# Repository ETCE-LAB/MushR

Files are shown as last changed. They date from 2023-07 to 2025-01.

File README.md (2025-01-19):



# MushR

MushR is a modular and scalable gourmet mushroom growing and
harvesting system that goes beyond the state of the art, which merely
monitors and controls the growing environment, by introducing an image
recognition system that determines when and which mushrooms are ready
to be harvested in conjunction with a proof-of-concept of an automated
mushroom harvesting mechanism for harvesting the mushrooms without
human interaction. The image recognition setup monitors the growing
status of the mushrooms and guides the harvesting process. We present
a Mask R-CNN model for the detection of oyster mushroom maturity as
well as a semi-automated harvesting system, integrating a Raspberry Pi
for control, an electrical switch, an air compressor, and a pneumatic
cylinder with a cutting knife to facilitate timely mushroom
harvesting. The modularity and scalability of the system allow for
industry-level usage and can be scaled according to the required
mushroom-growing systems within the facility.

The dataset created for this project focuses on capturing images of
the mushroom-growing environment from three different perspectives
within each of our two growth tents for mushroom production. Instead
of providing images of every individual bucket and mushroom, we
capture the overall scene and its variations. The images from each
perspective are captured simultaneously and automatically hourly. This
approach allows for monitoring the development and maturity of the
oyster mushrooms over time. We captured and accumulated 34,400 images
over ten months to ensure a comprehensive dataset.

- [Growchamber Setup](growchamber-setup/)
- [Automated Image Capture](automated-image-capture/) 

- [Lifecycle Assessment Calculations](lca-calculations/)
- MushR Digital Twin
  - [MushR Digital Twin API](https://github.com/ETCE-LAB/mushr-digitaltwin-api/tree/main)
  - [MushR Digital Twin Widgets for MyCodo](https://github.com/ETCE-LAB/mushr-digitaltwin-api/tree/main/mycodo)
- MushR Dataset
  - [Complete Un-Annotated RAW Images](https://www.kaggle.com/datasets/etcelab/mushr-project-raw-image-dataset-oyster-mushrooms)
  - [Images annotated for Mask R CNN](https://www.kaggle.com/datasets/etcelab/mushr-annotated-dataset-oyster-mushrooms)
  - [MushR Mask R CNN](https://github.com/ETCE-LAB/mushr-mask-r-cnn)
- Harvesting Setup
 - [Pneumatic Harvesting](pneumatic-harvesting/)
 - [Motorized Harvesting](motorized-harvesting/)

# Contributors (Past and Present)

1. Anant Sujatanagarjuna
2. Shohreh Kia
3. Harish Gundelli

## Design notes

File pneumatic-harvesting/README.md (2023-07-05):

## Contributors
  1. Shohreh Kia
  2. Anant Sujatanagarjuna

## Pneumatic Harvesting of Oyster Mushrooms

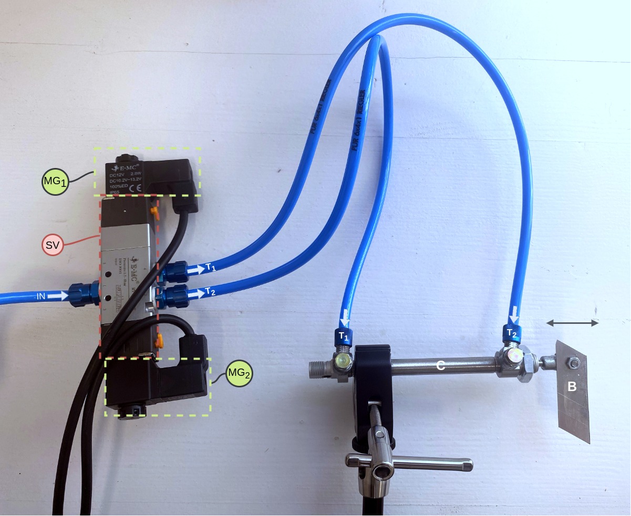
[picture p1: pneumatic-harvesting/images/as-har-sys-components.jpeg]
Pneumatic Harvesting Components 1

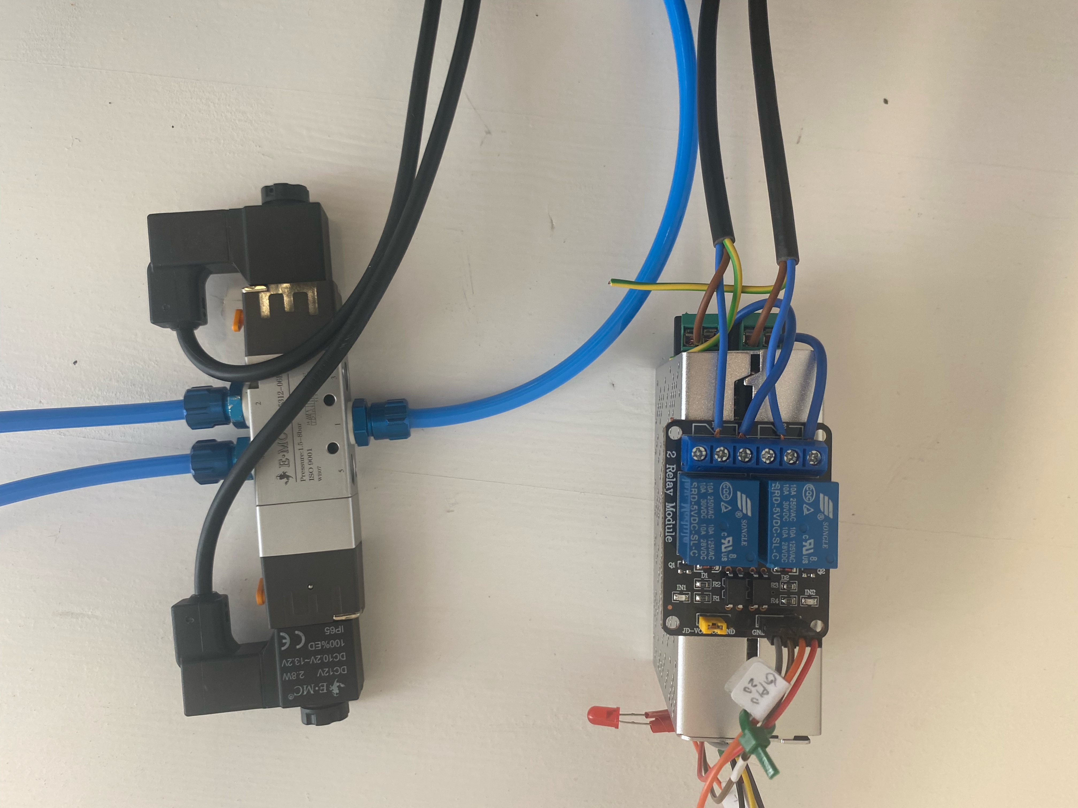
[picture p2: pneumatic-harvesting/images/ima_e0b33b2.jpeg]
Pneumatic Harvesting Components 2


The above figures show the components used to prototype a pneumatic
harvesting system for Oyster mushrooms.

## Working Principle

This system actuates a blade (B) which is mounted perpendicularly on a
bi-directional pneumatic cylinder (C). The cylinder is set up to
harvest oyster mushrooms growing from our developed mushroom pods. The
pneumatic tubes T1 and T2 control the motion of the pneumatic
cylinder. Depending on whether T1 or T2 is pressurized, the piston rod
moves outwards or inwards from the cylinder, respectively. When both
T1 and T2 are pressurized or depressurized, the piston is immobilized
or free to move, respectively.

For the purpose of harvesting, T1 and T2 must be pressurized and
depressurized alternatively. This is accomplished by the 5/3-way
solenoid valve (SV). Internally, two solenoids control the valves
pressurizing T1 and T2. These solenoids are activated by 12-volt DC
magnetic coils MG1 and MG2 . These coils are digitally controlled by
5-volt relay switches connected to a Raspberry Pi 4B, programmatically
controlling the entire setup.

For simplicity, we use a an analog joystick to control the 5-volt
relays, however it is also possible for them to be actuated remotely
and automatically.

## Connection Diagram

Connection Diagram

The above ciruit diagram was created using
[Fritzing](https://github.com/fritzing/).

`joystick_control.sh` is the accompanying control script.

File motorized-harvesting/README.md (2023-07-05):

## Contributors
  1. Shohreh Kia

## Motorized Harvesting of Oyster Mushrooms

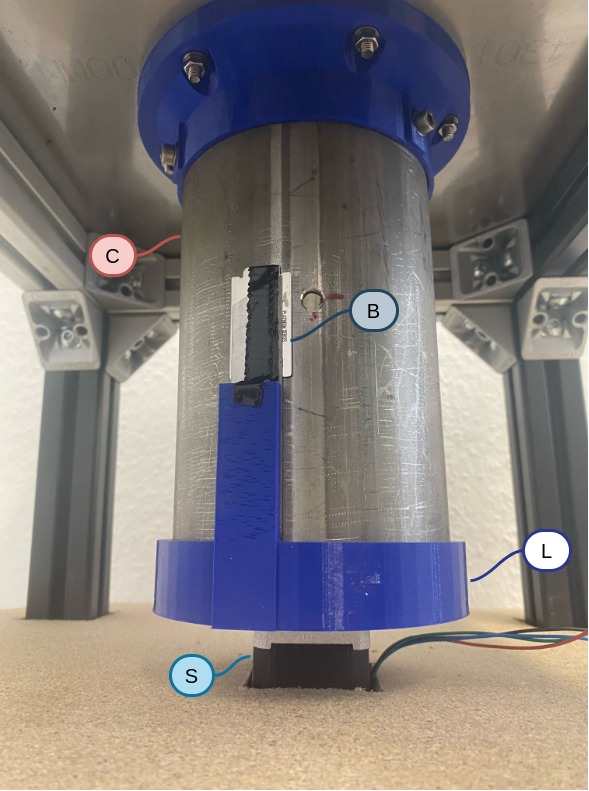
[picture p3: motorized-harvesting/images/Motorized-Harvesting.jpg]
Motorized Harvesting Components


The above figures show the components used to prototype a pneumatic
harvesting system for Oyster mushrooms.

## Working Principle

The above figure shows the major components of the developed motorized
harvesting system, which consists of a stainless steel cylinder (C)
with fruiting holes suspended from the ceiling of a stool constructed
using item profiles. The cylinder contains a plastic bag filled with a
substrate for oyster mushroom growth. These holes on the cylinder
aligned with the perforation in the plastic bag, allowing the
mushrooms to emerge and grow. A 3D-printed lid (L), matching the
diameter of the cylinder, seals the bottom to prevent substrate
spillage in case of damage to the bag. A stepper motor (S) is
installed underneath the suspended cylinder to drive a 3D-printed
plate, which vertically holds the blade (B).  The plate is
specifically designed to accommodate the motor, ensuring stability
during rotation.

The stepper motor initiates rotation, causing the blade to cut the
mushrooms protruding through the holes in the cylinder. We program the
motor to rotate in either direction to ensure successful
harvesting. Adjustments such as sharpening the knife and modifying the
motor’s speed can be made to optimize the system’s performance.

## Connection Diagram

Connection Diagram

## CAD Files

The CAD files for the 3D printed components used for this system can be found in [](cad/)

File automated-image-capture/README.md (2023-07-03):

# Table of Contents

1.  [Software Installation](#org174f0ca)
    1.  [Operating System](#org78977bb)
        1.  [Tent1Pi](#orgb3c0dfb)
        2.  [LightingPi](#orgb3e6948)
        3.  [Tent2Pi](#org14200cd)
2.  [Hardware Installation Guide](#orga6efd23)
    1.  [Focus adjustment](#org7833075)
    2.  [Waterproofing the cameras](#orgb9a1131)
    3.  [Installing the cameras in the tents](#org29d7754)
        1.  [Installing the aluminium mounts](#orga788bbe)
        2.  [Clamping the cameras](#org661947b)
    4.  [Raspberry Pi <-> Camera connection](#org06773e6)
    5.  [Lighting Setup](#org10030a2)

It is reccommended follow the following steps **IN ORDER**.

# Software Installation

## Operating System

-   The setup has only been tested with Raspberry Pi OS 32-bit on a
    Rpi4B (the version at the time of writing this guide is:
    <https://downloads.raspberrypi.org/raspios_armhf/images/raspios_armhf-2022-09-26/>)

-   Follow [this guide](https://www.raspberrypi.com/software/) to install your desired OS version.

-   Be sure to enable the SSH daemon and test that you are able to
    remotely log in to each pi using the password you chose during
    install.
    
        sudo systemctl enable sshd.service

-   Please also enable autologin (desktop/TTY) at least for [1.1.3](#org14200cd)
    
    For [1.1.1](#orgb3c0dfb) and [1.1.3](#org14200cd), you must verify whether the cameras are
    functioning using [this guide](https://www.raspberrypi.com/documentation/computers/camera_software.html) (might require a monitor and keyboard
    connected using a micro-HDMI cable).

-   Copy all the (required) scripts from this repository inside a new
    directory "~/scripts" on each pi.

-   Ensure that the latest version of wiringpi is installed on [1.1.1](#orgb3c0dfb)
    and [1.1.3](#org14200cd).
    
        cd /tmp
        wget https://project-downloads.drogon.net/wiringpi-latest.deb
        sudo dpkg -i wiringpi-latest.deb
    
    You might have to install `wget`:
    
        sudo apt install wget

-   Install imagemagick on [1.1.1](#orgb3c0dfb) and [1.1.3](#org14200cd).
    
        sudo apt install imagemagick

-   This folder contains all the scripts required for
    taking images. Briefly summarized, the main scripts are:
    1.  `arducam_multicamera.py` : Library used for taking images using
        the [Arducam Multicamera Board V2.2](https://www.arducam.com/product/multi-camera-v2-1-adapter-raspberry-pi/). This script is based on
        <https://github.com/ArduCAM/RaspberryPi/tree/master/Multi_Camera_Adapter/Multi_Adapter_Board_4Channel>.
        
        To change the way images are captured, you can create/edit the
        camera preset commands `FULL`, `PREVIEW` and `LOW`. More
        specifically, you must change `--awbgain` whenever the colour of
        the lights inside the tents is changed. This is used to manually
        change the colour balance of the images.
    
    2.  `mushrimager-multicam-noremote.sh`,
        `mushrimager-multicam-bothtents.sh` and
        `mushrimager-multicam-previewer.sh` are the currently relevant
        scripts for taking images.
    
    3.  `turn-off-lights.sh` and `turn-on-lights.sh` are used to control
        the lights.

-   Ensure that these scripts are executable
    
        chmod 755 <path to file>.sh
-   Note down the IP address of all raspberry pis.
    
        ip a | grep wlan

### Tent1Pi

Tent1Pi will be connected to the cameras 1A, 1B and 1C in Tent1.

1.  Ensure that `mushrimager-multicam-noremote.sh` is functional.

### LightingPi

The LightingPi uses a reverse engineered RGB5050 remote configuration
to control the RGB5050 lights in the tents.

1.  Wiring the KY005/KY-022

    Refer to this [manual](https://uelectronics.com/wp-content/uploads/2017/06/KY-005-Joy-IT.pdf) for general instructions, **however,** Lots of
    stuff there about the installation and initial configuration is
    **OUTDATED**. Use this guide instead (last tested 12.12.2022).
    
    Generally, connect 5V and GND on either the KY-022 (when reverse
    engineering a remote) or the KY005 (When using the rpi as a spoof of
    the remote) to a 5V/GND pin on the raspberry pi respectively.
    
    Connect GPIO pin 17 OR 18 on the raspberrypi to the KY-022/KY005
    respectively, depending on which one is needed. The KY-022 is only
    needed for [reverse engineering the remote](#org633485f), and is not needed later.
    
    1.  KY-005/KY-022 Configuration
    
        in /boot/config.txt: uncomment the following lines, and customize the
        pins accordingly, then REBOOT
        
            dtoverlay=gpio-ir,gpio_pin=17	 # for receiving data
            dtoverlay=gpio-ir-tx,gpio_pin=18   # for sending commands
        
        1.  KY-022 Only
        
            Test that the receiver is working:
            
                sudo apt update
                sudo apt install ir-keytable
            
                sudo ir-keytable -c -p all -t
            
            Then use some IR remote to send events to the IR receiver. The events
            should be displayed if all connections are correct.

2.  Installing Lirc

    -   State "LOGGED" from <span class="timestamp-wrapper"><span class="timestamp">[2022-08-18 Thu 14:12] </span></span>   
        As of today, lirc0 defaults to the transmitter, and lirc1 is the
        receiver
    
        sudo apt install lirc
    
    For setting up lirc for future IR transmitters
    Edit /etc/lirc/lirc<sub>options.conf</sub> and change the appropriate lines to
    the following, and REBOOT:

        ...
        driver	=	default
        ...
        device	=	/dev/lirc0
    
    For the receiver,
    
        sudo systemctl stop lircd.service
        sudo mode2 -d /dev/lirc1

3.  IR Remote Reverse Engineering

        irrecord -d /dev/lirc1 ~/IR-Codes-RGB5050-remote.conf
    
    When prompted, you can use key codes from the following:
    
        irrecord -l 
    
    Copy the file to /etc/lirc/lircd.conf, after backing up the original.

4.  IR Remote spoofing

    1.  To view available commands,
    
            irsend LIST <name of the remote set in lircd.conf> ""
    
    2.  To send a signal ONCE
    
            irsend SEND_ONCE <name of the remote set in lircd.conf> <name of command>
    
    3.  To start sending a signal continuously
    
            irsend SEND_START <name of the remote set in lircd.conf> <name of command>
    
    4.  To stop sending the previous continuous signal
    
            irsend SEND_STOP <name of the remote set in lircd.conf> <name of command>

5.  Current lircd config

    The currently configured /etc/lirc/lircd.conf file is as follows:

        # Please take the time to finish this file as described in
        # https://sourceforge.net/p/lirc-remotes/wiki/Checklist/
        # and make it available to others by sending it to
        # <lirc@bartelmus.de>
        #
        # This config file was automatically generated
        # using lirc-0.10.1(default) on Thu Aug 18 12:47:46 2022
        # Command line used: -d /dev/lirc1 /home/mushr/IR-codes-RGB5050-remote.conf
        # Kernel version (uname -r): 5.15.56-v7l+
        #
        # Remote name (as of config file): RGB5050remote
        # Brand of remote device, the thing you hold in your hand:
        # Remote device model nr:
        # Remote device info url:
        # Does remote device has a bundled capture device e. g., a
        #     usb dongle? :
        # For bundled USB devices: usb vendor id, product id
        #     and device string (use dmesg or lsusb):
        # Type of device controlled
        #     (TV, VCR, Audio, DVD, Satellite, Cable, HTPC, ...) :
        # Device(s) controlled by this remote:
        
        begin remote
        
          name  RGB5050remote
          bits           24
          flags SPACE_ENC|CONST_LENGTH
          eps            30
          aeps          100
        
          header       9059  4411
          one           647  1577
          zero          647   481
          ptrail        645
          repeat       9050  2157
          pre_data_bits   8
          pre_data       0x0
          gap          107539
          toggle_bit_mask 0x0
          frequency    38000
        
              begin codes
        	  KEY_POWER2               0xF7C03F 0x000000
        	  KEY_POWER                0xF740BF 0x000000
        	  KEY_BRIGHTNESSDOWN       0xF7807F 0x000000
        	  KEY_BRIGHTNESSUP         0xF700FF 0x000000
        	  KEY_PROG1                0xF7E01F 0x000000
        	  KEY_BLUE                 0xF7609F 0x000000
        	  KEY_GREEN                0xF7A05F 0x000000
        	  KEY_RED                  0xF720DF 0x000000
        	  KEY_YELLOW               0xF7906F 0x000000
              end codes
        
        end remote

### Tent2Pi

Tent1Pi will be connected to the cameras 1A, 1B and 1C in Tent1, and
also needs to be able to connect to [1.1.1](#orgb3c0dfb) and [1.1.2](#orgb3e6948)

While logged in to this pi,

1.  [Generate an ssh key](https://www.ssh.com/academy/ssh/keygen). e.g,
    
        ssh-keygen -t ed25519

2.  Use [ssh-copy-id](https://www.ssh.com/academy/ssh/keygen) to be able to access the other pis. e.g,
    
        ssh-copy-id ~/ssh/ed25519 pi@<ip address of Tent1Pi>
        ssh-copy-id ~/ssh/ed25519 pi@<ip address of LightingPi>

3.  In `mushrimager-multicam-bothtents.py`, you must change the IP
    addresses and usernames of [1.1.1](#orgb3c0dfb) and [1.1.2](#orgb3e6948) in order for this
    script to function correctly.

4.  Create a file "tucloud.txt" in the same folder with the credentials
    for the tucloud account as follows:
    
        machine tucloud.tu-clausthal.de login <username> password <password>
    
    Custom keys also work.

5.  Ensure that the system time is accurate, as the time is used to
    name the image files.

6.  With [1.1.1](#orgb3c0dfb) and [1.1.2](#orgb3e6948) also configured correctly, test the
    script `mushrimager-multicam-bothtents.py` without any arguments.

7.  Create a [cronjob](https://wiki.archlinux.org/title/Cron) for running this script periodically.
    
        crontab -e
    
    For example, this line will take an image every 15 minutes.
    
        */15    *       *       *       *       /home/pi/scripts/mushrimager-multicam-bothtents.sh

8.  Enable the user crontab as follows (this is the reason autologin is
    necessary):
    
        systemctl --user enable cron.service

9.  Software installation is complete.

# Hardware Installation Guide

## Focus adjustment

1.  Please refer to [this official guide](https://datasheets.raspberrypi.com/hq-camera/cs-mount-lens-guide.pdf) for attaching the lens to the HQ
    camera board.

2.  Measure the desired focal length needed for the cameras.

3.  The backfocus adjustment and lens focus adjustment must be
    calibrated manually for each camera based on the desired focus
    length. This process is repetitive (trial and error), and would
    require taking multiple images, hence depends upon [1](#org174f0ca).

4.  You can start a live preview for individual cameras using the
    `arducam_multicamera.py` script. (Run `python3
       arducam_multicamera.py -h` for details)

## Waterproofing the cameras

There are two [3d printed parts](CAD/)used per camera.

-   The **Grey part** is used to hold the lens inside the dome case. (Only
    fits the 120° Wide angle lens). It must be secured with a bit of
    duct tape along it's edges (to create a spongy, but more tight fit)
    inside the [Camera Dome Case](https://amzn.eu/d/iZtZ2rX), aligning the holes for the lens to
    capture images through. A small strip of cardboard might be required
    to fit this inside the dome case. **It is important that this part is
    tightly secured.**

-   The **Green part** keeps the camera board and lens in place at a 90°
    angle. The purpose of the 90° angle placement is to maximize the
    vertical field of view of the captured images, since the tents are
    more tall than they are wide.

-   The HQ camera board should be mounted so that the 200cm flex cable
    exits the camera board at a 90° angle. (Here is a nice [guide](https://thepihut.com/blogs/raspberry-pi-tutorials/how-to-replace-the-raspberry-pi-camera-cable) for
    connecting the cable to the camera board) **PS: Be very careful with
    the black connector**. It is possible to damage it in such a way that
    it does not hold the ribbon cable anymore. For the same reason, do
    not pull too much on the ribbon cable while it is connected.

-   (Optional) A small silica gel pack can be fit right behind the
    camera board to prevent accidental spillage.

-   Use a plastic sheet to waterproof the rest of the camera board from
    the outside (with a healthy amount of duct tape :). Connect one side
    of the 200cm flex cable before sealing it (for obvious reasons).

-   **It is important to not fold/damage the cable in any way.**

## Installing the cameras in the tents

### Installing the aluminium mounts

Two aluminium mounts (L=Long & S=short) are used (per tent) to mount
the center facing camera (1.B & 2.B).

1.  The aluminium mounts are currently mounted to the tents using zip
    ties.

2.  They are already screwed in together (thanks to Johannes!)

3.  Mount L needs to be hung vertically, (relatively) in the center of
    each tent. The angle does not have to be perfect.

4.  Mount S needs to be zip tied to either the left or the right side
    of the tent. **PS: It can be beneficial to keep both zip ties a bit
    loose, to be able to move them around while changing camera
    angles.**

5.  Mount S would probably have to be duct-taped to the side of the
    tent to keep it in place.

### Clamping the cameras

1.  Loosen the ball and socket joint of the [clamp](https://amzn.eu/d/8iBo7e4).
2.  Screw in the clamp to the bottom of the Dome Case. (Do this outside
    the tent, since a bit of rubber residue tends to rub off when doing
    this.)
3.  With the ball and socket joint still slightly loose (**but still
    holding the dome case firmly**), clamp the setup to any desired
    location. You might have to experiment a little bit to get the
    camera lens as far away from the mushrooms inside the tent as
    possible.
4.  Once a desired angle is reached, tighten the ball and socket joint
    using the screw.

## Raspberry Pi <-> Camera connection

1.  Thread the ribbon cables through any desired port (tent port).

2.  Connect the Multicamera board ports "A", "B" and "C" to the ribbon
    cables connected to the camera housing labelled "X.A", "X.B", "X.C".
    
    Here, X is either 1 or 2 depending on which tent the camera
    housing is in.

3.  There is a visual hardware assembly guide in drawer "#2".

4.  Power on the raspberry pi.

## Lighting Setup

-   Make sure that the RGB5050 lights are set to "yellow".

-   The RGB5050 receiver should also be positioned to be able to receive
    signals from [1.1.2](#orgb3e6948).

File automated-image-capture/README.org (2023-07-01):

:PROPERTIES:
:ID:       3733c2ed-6d2a-433d-829f-105ee944b569
:END:
#+title: MushR: Camera Setup: Installation Guide
#+author: Anant Sujatanagarjuna

It is reccommended follow the following steps *IN ORDER*.

* Software Installation
** Operating System
- The setup has only been tested with Raspberry Pi OS 32-bit on a
  Rpi4B (the version at the time of writing this guide is:
  https://downloads.raspberrypi.org/raspios_armhf/images/raspios_armhf-2022-09-26/)

- Follow [[https://www.raspberrypi.com/software/][this guide]] to install your desired OS version.

- Be sure to enable the SSH daemon and test that you are able to
  remotely log in to each pi using the password you chose during
  install.
  #+begin_src sh
    sudo systemctl enable sshd.service
  #+end_src

- Please also enable autologin (desktop/TTY) at least for [[Tent2Pi]]

  For [[Tent1Pi]] and [[Tent2Pi]], you must verify whether the cameras are
  functioning using [[https://www.raspberrypi.com/documentation/computers/camera_software.html][this guide]] (might require a monitor and keyboard
  connected using a micro-HDMI cable).

- Clone the MushR project repository [[https://gitlab.tu-clausthal.de/dfb12/mushr][mushr.git]], in all pis. Copy all
  the scripts inside the "camera-setup" directory inside a new
  directory "~/scripts" on each pi.

- Ensure that the latest version of wiringpi is installed on [[Tent1Pi]]
  and [[Tent2Pi]].

  #+begin_src sh
    cd /tmp
    wget https://project-downloads.drogon.net/wiringpi-latest.deb
    sudo dpkg -i wiringpi-latest.deb
  #+end_src

  You might have to install =wget=:
  #+begin_src sh
    sudo apt install wget
  #+end_src

- Install imagemagick on [[Tent1Pi]] and [[Tent2Pi]].
  #+begin_src sh
    sudo apt install imagemagick
  #+end_src

- The "camera-setup" folder contains all the scripts required for
  taking images. Briefly summarized, the main scripts are:
  1. =arducam_multicamera.py= : Library used for taking images using
     the [[https://www.arducam.com/product/multi-camera-v2-1-adapter-raspberry-pi/][Arducam Multicamera Board V2.2]]. This script is based on
     [[https://github.com/ArduCAM/RaspberryPi/tree/master/Multi_Camera_Adapter/Multi_Adapter_Board_4Channel]].

     To change the way images are captured, you can create/edit the
     camera preset commands =FULL=, =PREVIEW= and =LOW=. More
     specifically, you must change =--awbgain= whenever the colour of
     the lights inside the tents is changed. This is used to manually
     change the colour balance of the images.

  2. =mushrimager-multicam-noremote.sh=,
     =mushrimager-multicam-bothtents.sh= and
     =mushrimager-multicam-previewer.sh= are the currently relevant
     scripts for taking images.

  3. =turn-off-lights.sh= and =turn-on-lights.sh= are used to control
     the lights.

- Ensure that these scripts are executable
  #+begin_src sh
    chmod 755 <path to file>.sh
  #+end_src
- Note down the IP address of all raspberry pis.
  #+begin_src sh
    ip a | grep wlan
  #+end_src
 
*** Tent1Pi
Tent1Pi will be connected to the cameras 1A, 1B and 1C in Tent1.

1. Ensure that =mushrimager-multicam-noremote.sh= is functional.

*** LightingPi

The LightingPi uses a reverse engineered RGB5050 remote configuration
to control the RGB5050 lights in the tents.

**** Wiring the KY005/KY-022

Refer to this [[https://uelectronics.com/wp-content/uploads/2017/06/KY-005-Joy-IT.pdf][manual]] for general instructions, *however,* Lots of
stuff there about the installation and initial configuration is
*OUTDATED*. Use this guide instead (last tested 12.12.2022).

Generally, connect 5V and GND on either the KY-022 (when reverse
engineering a remote) or the KY005 (When using the rpi as a spoof of
the remote) to a 5V/GND pin on the raspberry pi respectively.

Connect GPIO pin 17 OR 18 on the raspberrypi to the KY-022/KY005
respectively, depending on which one is needed. The KY-022 is only
needed for [[IR Remote Reverse Engineering][reverse engineering the remote]], and is not needed later.

***** KY-005/KY-022 Configuration

in /boot/config.txt: uncomment the following lines, and customize the
pins accordingly, then REBOOT

#+begin_src conf
  dtoverlay=gpio-ir,gpio_pin=17	 # for receiving data
  dtoverlay=gpio-ir-tx,gpio_pin=18   # for sending commands
#+end_src

****** KY-022 Only
Test that the receiver is working:

#+begin_src sh
  sudo apt update
  sudo apt install ir-keytable
#+end_src

#+begin_src sh
  sudo ir-keytable -c -p all -t
#+end_src

Then use some IR remote to send events to the IR receiver. The events
should be displayed if all connections are correct.

**** Installing Lirc

- State "LOGGED" from [2022-08-18 Thu 14:12] \\
  As of today, lirc0 defaults to the transmitter, and lirc1 is the
  receiver
  
#+begin_src sh
  sudo apt install lirc
#+end_src

For setting up lirc for future IR transmitters
Edit /etc/lirc/lirc_options.conf and change the appropriate lines to
the following, and REBOOT:
#+begin_src conf

  ...
  driver	=	default
  ...
  device	=	/dev/lirc0
#+end_src

For the receiver,

#+begin_src sh
  sudo systemctl stop lircd.service
  sudo mode2 -d /dev/lirc1
#+end_src

**** IR Remote Reverse Engineering

#+begin_src sh
  irrecord -d /dev/lirc1 ~/IR-Codes-RGB5050-remote.conf
#+end_src

When prompted, you can use key codes from the following:

#+begin_src sh
  irrecord -l 
#+end_src

Copy the file to /etc/lirc/lircd.conf, after backing up the original.

**** IR Remote spoofing

***** To view available commands,

#+begin_src sh
  irsend LIST <name of the remote set in lircd.conf> ""
#+end_src

***** To send a signal ONCE

#+begin_src sh
  irsend SEND_ONCE <name of the remote set in lircd.conf> <name of command>
#+end_src

***** To start sending a signal continuously
#+begin_src sh
  irsend SEND_START <name of the remote set in lircd.conf> <name of command>
#+end_src

***** To stop sending the previous continuous signal
#+begin_src sh
  irsend SEND_STOP <name of the remote set in lircd.conf> <name of command>
#+end_src

**** Current lircd config

The currently configured /etc/lirc/lircd.conf file is as follows:

#+begin_src conf

  # Please take the time to finish this file as described in
  # https://sourceforge.net/p/lirc-remotes/wiki/Checklist/
  # and make it available to others by sending it to
  # <lirc@bartelmus.de>
  #
  # This config file was automatically generated
  # using lirc-0.10.1(default) on Thu Aug 18 12:47:46 2022
  # Command line used: -d /dev/lirc1 /home/mushr/IR-codes-RGB5050-remote.conf
  # Kernel version (uname -r): 5.15.56-v7l+
  #
  # Remote name (as of config file): RGB5050remote
  # Brand of remote device, the thing you hold in your hand:
  # Remote device model nr:
  # Remote device info url:
  # Does remote device has a bundled capture device e. g., a
  #     usb dongle? :
  # For bundled USB devices: usb vendor id, product id
  #     and device string (use dmesg or lsusb):
  # Type of device controlled
  #     (TV, VCR, Audio, DVD, Satellite, Cable, HTPC, ...) :
  # Device(s) controlled by this remote:

  begin remote

    name  RGB5050remote
    bits           24
    flags SPACE_ENC|CONST_LENGTH
    eps            30
    aeps          100

    header       9059  4411
    one           647  1577
    zero          647   481
    ptrail        645
    repeat       9050  2157
    pre_data_bits   8
    pre_data       0x0
    gap          107539
    toggle_bit_mask 0x0
    frequency    38000

        begin codes
            KEY_POWER2               0xF7C03F 0x000000
            KEY_POWER                0xF740BF 0x000000
            KEY_BRIGHTNESSDOWN       0xF7807F 0x000000
            KEY_BRIGHTNESSUP         0xF700FF 0x000000
            KEY_PROG1                0xF7E01F 0x000000
            KEY_BLUE                 0xF7609F 0x000000
            KEY_GREEN                0xF7A05F 0x000000
            KEY_RED                  0xF720DF 0x000000
            KEY_YELLOW               0xF7906F 0x000000
        end codes

  end remote

#+end_src

*** Tent2Pi
Tent1Pi will be connected to the cameras 1A, 1B and 1C in Tent1, and
also needs to be able to connect to [[Tent1Pi]] and [[LightingPi]]

While logged in to this pi,

1. [[https://www.ssh.com/academy/ssh/keygen][Generate an ssh key]]. e.g,

   #+begin_src sh
     ssh-keygen -t ed25519
   #+end_src

2. Use [[https://www.ssh.com/academy/ssh/keygen][ssh-copy-id]] to be able to access the other pis. e.g,

   #+begin_src sh
     ssh-copy-id ~/ssh/ed25519 pi@<ip address of Tent1Pi>
     ssh-copy-id ~/ssh/ed25519 pi@<ip address of LightingPi>
   #+end_src

3. In =mushrimager-multicam-bothtents.py=, you must change the IP
   addresses and usernames of [[Tent1Pi]] and [[LightingPi]] in order for this
   script to function correctly.

4. Create a file "tucloud.txt" in the same folder with the credentials
   for the tucloud account as follows:

   #+begin_src text
     machine tucloud.tu-clausthal.de login <username> password <password>
   #+end_src

   Custom keys also work.

5. Ensure that the system time is accurate, as the time is used to
   name the image files.

6. With [[Tent1Pi]] and [[LightingPi]] also configured correctly, test the
   script =mushrimager-multicam-bothtents.py= without any arguments.

7. Create a [[https://wiki.archlinux.org/title/Cron][cronjob]] for running this script periodically.
   #+begin_src sh
     crontab -e
   #+end_src

   For example, this line will take an image every 15 minutes.
   #+begin_src text
   */15    *       *       *       *       /home/pi/scripts/mushrimager-multicam-bothtents.sh
   #+end_src

8. Enable the user crontab as follows (this is the reason autologin is
   necessary):
   #+begin_src sh
     systemctl --user enable cron.service
   #+end_src

9. Software installation is complete.

* Hardware Installation Guide
** Focus adjustment

1. Please refer to [[https://datasheets.raspberrypi.com/hq-camera/cs-mount-lens-guide.pdf][this official guide]] for attaching the lens to the HQ
   camera board.

2. Measure the desired focal length needed for the cameras.
   
3. The backfocus adjustment and lens focus adjustment must be
   calibrated manually for each camera based on the desired focus
   length. This process is repetitive (trial and error), and would
   require taking multiple images, hence depends upon [[Software
   Installation]].

4. You can start a live preview for individual cameras using the
   =arducam_multicamera.py= script. (Run =python3
   arducam_multicamera.py -h= for details)

** Waterproofing the cameras

There are two 3d printed parts used per camera.

- The *Grey part* is used to hold the lens inside the dome case. (Only
  fits the 120° Wide angle lens). It must be secured with a bit of
  duct tape along it's edges (to create a spongy, but more tight fit)
  inside the [[https://amzn.eu/d/iZtZ2rX][Camera Dome Case]], aligning the holes for the lens to
  capture images through. A small strip of cardboard might be required
  to fit this inside the dome case. *It is important that this part is
  tightly secured.*
  
- The *Green part* keeps the camera board and lens in place at a 90°
  angle. The purpose of the 90° angle placement is to maximize the
  vertical field of view of the captured images, since the tents are
  more tall than they are wide.

- The HQ camera board should be mounted so that the 200cm flex cable
  exits the camera board at a 90° angle. (Here is a nice [[https://thepihut.com/blogs/raspberry-pi-tutorials/how-to-replace-the-raspberry-pi-camera-cable][guide]] for
  connecting the cable to the camera board) *PS: Be very careful with
  the black connector*. It is possible to damage it in such a way that
  it does not hold the ribbon cable anymore. For the same reason, do
  not pull too much on the ribbon cable while it is connected.

- (Optional) A small silica gel pack can be fit right behind the
  camera board to prevent accidental spillage.

- Use a plastic sheet to waterproof the rest of the camera board from
  the outside (with a healthy amount of duct tape :). Connect one side
  of the 200cm flex cable before sealing it (for obvious reasons).

- *It is important to not fold/damage the cable in any way.*

** Installing the cameras in the tents

*** Installing the aluminium mounts

Two aluminium mounts (L=Long & S=short) are used (per tent) to mount
the center facing camera (1.B & 2.B).

1. The aluminium mounts are currently mounted to the tents using zip
   ties.

2. They are already screwed in together (thanks to Johannes!)

3. Mount L needs to be hung vertically, (relatively) in the center of
   each tent. The angle does not have to be perfect.

4. Mount S needs to be zip tied to either the left or the right side
   of the tent. *PS: It can be beneficial to keep both zip ties a bit
   loose, to be able to move them around while changing camera
   angles.*

5. Mount S would probably have to be duct-taped to the side of the
   tent to keep it in place.

*** Clamping the cameras

1. Loosen the ball and socket joint of the [[https://amzn.eu/d/8iBo7e4][clamp]].
2. Screw in the clamp to the bottom of the Dome Case. (Do this outside
   the tent, since a bit of rubber residue tends to rub off when doing
   this.)
3. With the ball and socket joint still slightly loose (*but still
   holding the dome case firmly*), clamp the setup to any desired
   location. You might have to experiment a little bit to get the
   camera lens as far away from the mushrooms inside the tent as
   possible.
4. Once a desired angle is reached, tighten the ball and socket joint
   using the screw.

** Raspberry Pi <-> Camera connection

1. Thread the ribbon cables through any desired port (tent port).

2. Connect the Multicamera board ports "A", "B" and "C" to the ribbon
   cables connected to the camera housing labelled "X.A", "X.B", "X.C".

   Here, X is either 1 or 2 depending on which tent the camera
   housing is in.

3. There is a visual hardware assembly guide in drawer "#2".

4. Power on the raspberry pi.

** Lighting Setup
- Make sure that the RGB5050 lights are set to "yellow".

- The RGB5050 receiver should also be positioned to be able to receive
  signals from [[LightingPi]].

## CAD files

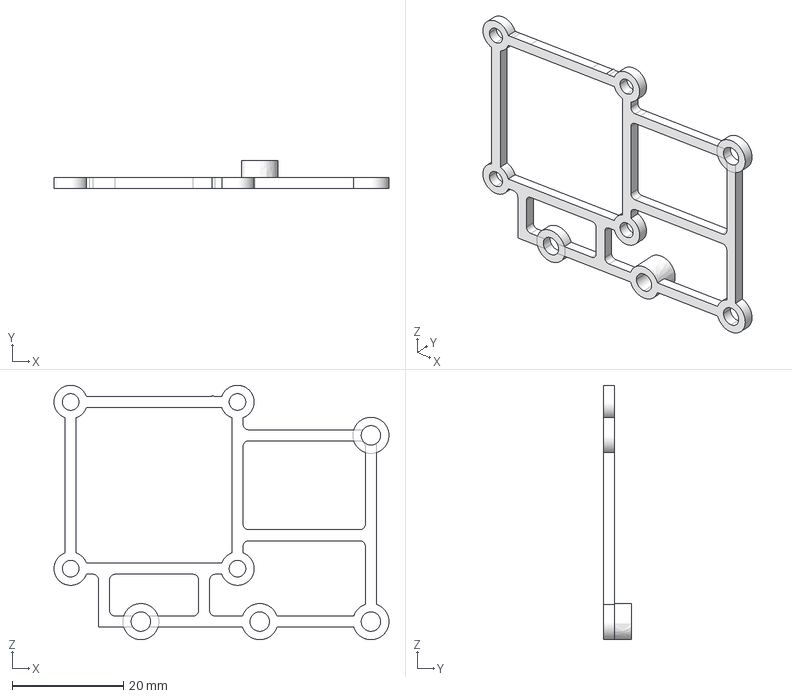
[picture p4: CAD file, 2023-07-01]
automated-image-capture/CAD/framePCB.stp
60.2 x 5.00 x 45.7 mm

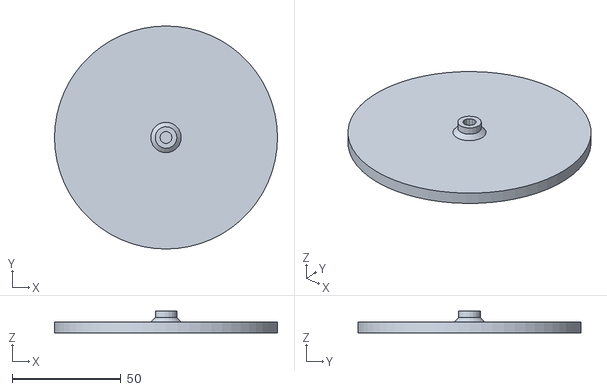
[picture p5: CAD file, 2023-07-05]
motorized-harvesting/cad/bottom.stl
102.5 x 102.5 x 10.0

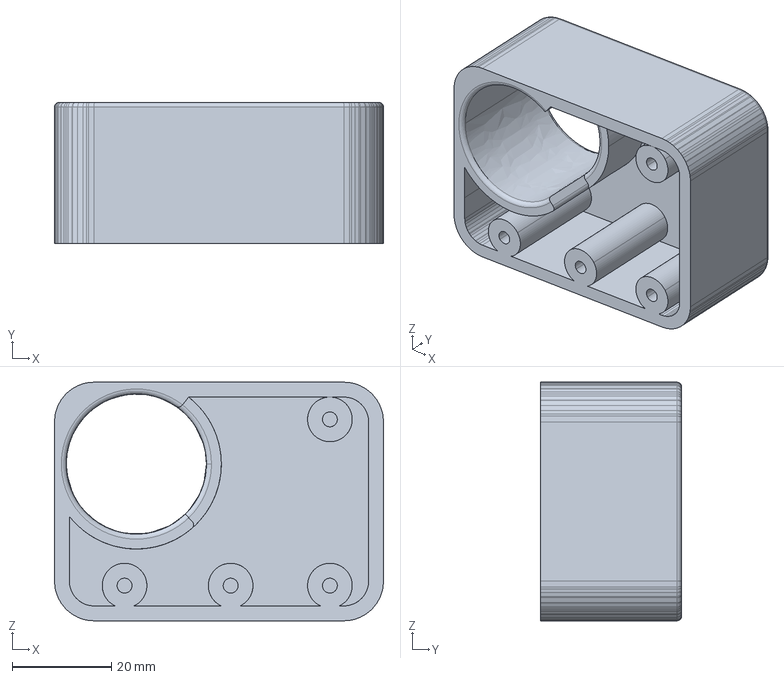
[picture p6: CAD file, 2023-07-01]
automated-image-capture/CAD/GP8_Case.stp
66.3 x 28.5 x 48.1 mm

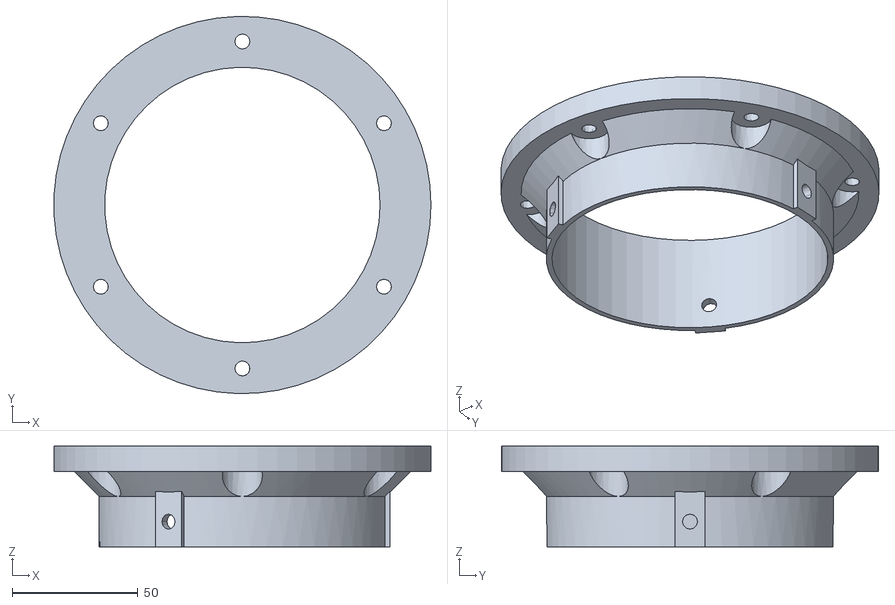
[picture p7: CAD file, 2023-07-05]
motorized-harvesting/cad/holding ring.stl
149.9 x 149.9 x 40.0

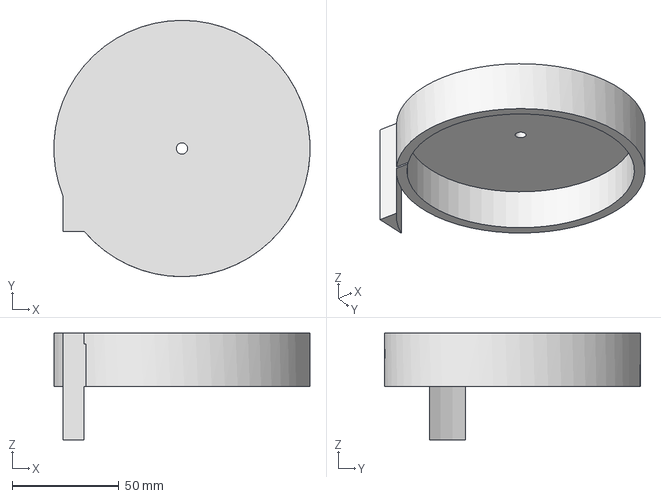
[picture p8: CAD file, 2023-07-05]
motorized-harvesting/cad/Disc.stp
119.9 x 120.0 x 50.0 mm

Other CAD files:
motorized-harvesting/cad/Assembly3.iam
motorized-harvesting/cad/Disc.ipt
motorized-harvesting/cad/Disc.stl
motorized-harvesting/cad/Pipe.ipt
motorized-harvesting/cad/bottom.ipt
motorized-harvesting/cad/holding ring.ipt
motorized-harvesting/cad/uppe sheet.ipt

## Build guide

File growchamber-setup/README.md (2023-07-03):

# Environment Monitor for MushR  with Humidity controller, Temperature Controller, and Cheese Effect while capturing Photo 

Mushrooms grow in a humid and warm environment. for optimal growth of mushrooms humidity and temperature has to be maintained at higher levels to support proper growth.
 
To control humidity and Temperature, MushR used Mycodo (https://github.com/kizniche/Mycodo)  with a mushr specific feature we call, "Cheese Effect". This is implemented to remove noise from the captured photo caused due to high humidity inside the tent. MushR cameras capture images every hour so this effect is effective from 10 minutes before the turn of the hour to 2 minutes past. Also see (https://github.com/ETCE-LAB/MushR/tree/grow-chamber-documentation#automated-image-capture).

#### List of Contributors
	
1. Harish Gundelli

#### Required Hardware

1. Raspberry pi 4 model b, Raspberry pi case
2. SD card 8-32 Gb,
3. Two DHT22 Sensors ( for 2 tents),
4.  Humidifiers, Fans, water Tanks (60ltrs)
5.  Grow tent Heaters,
6.  Smart plugs / relays
7.  Jumper cables 
8.  Inkbird * 2 

Step 1.
Installing Raspberry Pi OS using the following official raspberry pi website

   [Raspberrypi official Website](https://www.raspberrypi.com/documentation/computers/getting-started.html)

step 2.

 Install latest version of mycodo into the raspian os from official mycodo github repository

   [MyCodo official Website](https://github.com/kizniche/Mycodo)

step 3.
  
  connect DHT 22 sensors using following circuit diagram
  
   

step 4. 
  
  Configure the DHT22 sensors as Inputs in the mycodo using the following tutorial
  
   [click here](input/readme.md)
  
Step 5
   Configure the smart plugs as outputs in the mycodo using the following tutorial
   
   [click here](smartplugs/readme.md)
   
   Smart plugs are used for turning on/off the humidifiers when required
   
Step 6

   try reading the simple algorithm before you start the next tutorial
   [click here](overview%20algo/readme.md)
   
   Step 6.1 
   
   Configure humidity control as function in mycodo
     
   [click here](function/readme.md)

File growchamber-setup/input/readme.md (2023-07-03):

# Adding Humidity, Temperature Sensor in mycodo 

We used DHT22 for measuring the accurate temperature, Humidity inside the Tents. Each tent is equipped with one DHT22 sensor. These sensors are added as input in mycodo.
Follow these steps
step 1.	Navigate to mycodo IP address in a browser 

step 2.	 Click "Setup"		
           
  	<p align="center">Step 2 Screenshot </p>
step 3. 
	Click "Input"
     	
           <p align="center">Step 3 Screenshot </p>

step 4.	In the Input page Click on the dropdown box shown below

 <p align="center">Step 4 Screenshot </p>

step 5. Select "AOSONG: DHT22: Humidity/Temperature (pigpio) [GPIO] ” from the dropdown list 
 
 
 <p align="center">Step 5 Screenshot </p>
 
step 6.Wait for the libraries to download and install after successful installation click on Add button shown below


  <p align="center">Step 6 Screenshot </p>

step 7. Click on gear icon for the newly added DHt22 sensor listed as following

<p align="center">Step 7 Screenshot </p>

step 8.	in the pin field enter the GPIO pin used for DHT22 SENSOR (in the example we used pin no 10)

<p align=center“> step 8 Screenshot </p>

step 9.Click on the Save button to successfully save the newly added sensor configuration

 <p align="center"> step 9 Screenshot </p>

step 10. Click "Close“ button to close the input configuration: DHT 22 screen

 <p align="center">  Step  10 Screenshot </p>

step 11. Click on Activate button for adding sensor to Dashboard and start measuring values

<p align="center">  Step  11 Screenshot </p>

step 12. To view the live measurements from the newly activated DHT22  sensor Click on "Data"

<p align="center">  Step  12 Screenshot </p>

step 13. Click on live measurements option in dropdown box

<p align="center">  Step  13 Screenshot </p>

step 14.newly added DHT22 sensor will display the values in the current screen

Final screen with DHT22 sensor displaying the current measurements

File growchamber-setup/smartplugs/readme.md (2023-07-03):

# Adding Humdifier, Ventilator to mycodo 
We used TP-Link Tapo WLAN Smart Socket, Smart Home Wi-Fi Socket  for controlling the Humidifier, Fan for regulating the humidity inside the tents. Each tent is equipped with individual Humidifier, Fan both are connected to smart plug,  water tank with capacity of 60 Litres. Using  the output function in mycodo we can turn on, off the humidifiers, fan at required time.
Follow these steps for adding the smart socket as output to the mycodo 

Step 1.	Navigate to mycodo IP address in a browser 

Step 2.	 Click "Setup"	


<p align=”center”>Step 2 Screenshot </p>

Step 3. Click on "Output"


<p align=”center”>Step 3 Screenshot </p>

Step 4.	Click "Output: Select One" dropdown list


<p align=”center”>Step 4 Screenshot </p>

Step 5.	Select "On/Off: Python Code [PYTHON]" in the dropdown list


<p align=”center”>Step 5 Screenshot </p>

Step 6.	Click Add button after selecting the "On/Off: Python Code [PYTHON]"


<p align=”center”>Step 6 Screenshot </p>	

Step 7.	Click on the Gear icon in the newly added output device



						<p align=”center”>Step 7 Screenshot </p>
            
Step 8. In the new screen Click on the "On Command" field  and delete all its content  



<p align=”center”>Step 8 Screenshot </p>

step 9.	Paste the following code snippet into the text box

                      sys.path.insert(1, '/usr/local/lib/python3.9/dist-packages')
                      from PyP100 import PyP100      #pip install PyP100 
                      log_string = "ID: {id}: ON".format(id=output_id)
                      self.logger.info(log_string)

                      p100 = PyP100.P100("smart plug ip address", "tplink user id", "password") #Creating a P100 plug object

                      p100.handshake() #Creates the cookies required for further methods
                      p100.login() #Sends credentials to the plug and creates AES Key and IV for further methods

                      p100.turnOn() #Sends the turn on request
#end code smart plug on 

step 10.	Then Click on the "Off Command" field and delete all its contents then paste the following code snippet


<p align=”center”>Step 10 Screenshot </p>
         
#off code snippet
```python
   #  Copyright (C) 2022, 2023 Harish Gundelli
    
   #  This program is free software: you can redistribute it and/or modify
   #  it under the terms of the GNU Affero General Public License as
   #  published by the Free Software Foundation, either version 3 of the
   #  License, or (at your option) any later version.
    
   #  This program is distributed in the hope that it will be useful,
   #  but WITHOUT ANY WARRANTY; without even the implied warranty of
   #  MERCHANTABILITY or FITNESS FOR A PARTICULAR PURPOSE.  See the
   #  GNU Affero General Public License for more details.
    
   #  You should have received a copy of the GNU Affero General Public License
   #  along with this program.  If not, see <https://www.gnu.org/licenses/>.

   sys.path.insert(1, '/usr/local/lib/python3.9/dist-packages')
   from PyP100 import PyP100
   log_string = "ID: {id}: OFF".format(id=output_id)
   self.logger.info(log_string)
   p100 = PyP100.P100("smart plug ip address", "tplink user id", "password") #Creating a P100 plug object ,replace ip address and userid , password.

   p100.handshake() #Creates the cookies required for further methods
   p100.login() #Sends credentials to the plug and creates AES Key and IV for further methods

   p100.turnOff() #Sends the turn off request
   p100.getDeviceInfo()
```

Step 11.	Click on save button and wait for the mycodo then click on the close button  
          
          <p align=”center”>Step 11 Screenshot 1 </p>
          
          <p align=”center”>Step 11 Screenshot 2 </p>

Step 12.	Then verify the output using on, off buttons in the newly added output device

<p align=”center”>Step 12 on Screenshot </p>


<p align=”center”>Step 12 off Screenshot </p> 

You have successfully added smart plug as output.

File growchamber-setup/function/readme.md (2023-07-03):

# Creating Humidity Controller and Cheese Effect while capturing Photo

Humidity controller is designed to maintain 85% to 90% humidity inside the grow tent and while keeping the high humidity inside the tents we observed  photos captured for AI training are blurry and full of moisture which is resulted with noisy images. In conclusion AI was unable to train on noisy images with high humidity 
As  solution to this problem we decided to remove humidity during the photo capturing from the tent we named this solution as cheese effect as we say cheese before capturing a photo.
every hour at 00 minutes and 00 seconds our three cameras capture the images of mushrooms growing inside the tents.
 
Step 1.	Navigate to mycodo IP address in a browser. 

Step 2.	 Click "Setup"	  
 
 
Screenshot step 2

Step 3.	click on function
 
Screenshot step 3

Step 4.	in the  newly loaded “Function” page click on the function: Select One dropdown box


Screenshot step 4

Step 5.	select Conditional Controller as shown below. 


Screenshot step 5

Step 6.	Then Click on Add button 

Screenshot step 6

Step 7.	Click on the new added conditional controller gear icon. 

Screenshot step 7

Step 8.	Then paste the following code in the Run python code text box in the newly appeared screen. 

Screenshot step 8

Code for step 8

```python
   #  Copyright (C) 2022, 2023 Harish Gundelli
    
   #  This program is free software: you can redistribute it and/or modify
   #  it under the terms of the GNU Affero General Public License as
   #  published by the Free Software Foundation, either version 3 of the
   #  License, or (at your option) any later version.
    
   #  This program is distributed in the hope that it will be useful,
   #  but WITHOUT ANY WARRANTY; without even the implied warranty of
   #  MERCHANTABILITY or FITNESS FOR A PARTICULAR PURPOSE.  See the
   #  GNU Affero General Public License for more details.
    
   #  You should have received a copy of the GNU Affero General Public License
   #  along with this program.  If not, see <https://www.gnu.org/licenses/>.

   now = datetime.now()
   min1 = now.strftime("%M")
   mini=int(min1)
   self.logger.info("This INFO log entry will appear in the Daemon Log")
   self.run_loop_count += 1  #Counts how many times the run code has been executed
   measurement = self.condition("a0792977")   # Replace ID with correct Conditional ID
   self.logger.info(f"Measurement value is {measurement}")
   if mini > 50:
   self.run_action("81dd30f8", message=self.message)
   if measurement is not None:  # If a measurement exists
   self.message += "This message appears in email alerts and notes.\n"
   if measurement < 82:  # If the measurement is less than 85
   if mini < 50:
   if mini > 2:
       self.message += f"Measurement is too Low! Measurement is {measurement} and outside photo period\n"
       self.run_action("d29201ec", message=self.message)  # Run all actions sequentially
   elif measurement > 87:  # Else If the measurement is greater than 90
   self.message += f"Measurement is too High! Measurement is {measurement}\n"
   #Replace "qwer5678" with an Action ID
   self.run_action("81dd30f8", message=self.message)
   ```

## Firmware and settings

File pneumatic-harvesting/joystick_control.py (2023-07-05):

#!/usr/bin/python
# coding=utf-8

#  Copyright (C) 2022, 2023 Anant Sujatanagarjuna

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

import time
import board
import busio
import adafruit_ads1x15.ads1115 as ADS
from adafruit_ads1x15.analog_in import AnalogIn
import RPi.GPIO as GPIO

BLADE_OUT = 21
BLADE_IN = 20
Button_PIN = 24
ARMED_LED_INDICATOR = 23

ARMED = False
pressed_counter = 0
delayTime = 0.1
armTime = 1 # Seconds
exitTime = 5 # Seconds

i2c = busio.I2C(board.SCL, board.SDA)

ads = ADS.ADS1115(i2c)

GPIO.setwarnings(True)
GPIO.setmode(GPIO.BCM)

time.sleep(2)

GPIO.setup(BLADE_OUT, GPIO.OUT)
GPIO.setup(BLADE_IN, GPIO.OUT)
GPIO.setup(ARMED_LED_INDICATOR, GPIO.OUT)
GPIO.setup(Button_PIN, GPIO.IN, pull_up_down = GPIO.PUD_UP)

# Create single-ended input on channels
chan0 = AnalogIn(ads, ADS.P0)
chan1 = AnalogIn(ads, ADS.P1)
chan2 = AnalogIn(ads, ADS.P2)
chan3 = AnalogIn(ads, ADS.P3)

def turn_both_off():
    GPIO.output(BLADE_OUT, GPIO.HIGH)
    GPIO.output(BLADE_IN, GPIO.HIGH)

def blade_out():
    turn_both_off()
    GPIO.output(BLADE_OUT, GPIO.LOW)

def blade_in():
    turn_both_off()
    GPIO.output(BLADE_IN, GPIO.LOW)

def armed_led_indicator_on():
    GPIO.output(ARMED_LED_INDICATOR, GPIO.HIGH)

def armed_led_indicator_off():
    GPIO.output(ARMED_LED_INDICATOR, GPIO.LOW)

button_pressed = False

turn_both_off()

for _ in range(5):
    armed_led_indicator_on()
    time.sleep(0.2)
    armed_led_indicator_off()
    time.sleep(0.2)

while True:

    time.sleep(delayTime/2)
    #current values are recorded
    X, Y = chan0.voltage, chan1.voltage
    x = '%.2f' % chan0.voltage
    y = '%.2f' % chan1.voltage
 
    # Output to console
    
    if GPIO.input(Button_PIN) == True:
        print ("X-axis:", x, "V, ", "Y-axis:", y, "V, Button: not pressed")
        button_pressed = False
        if pressed_counter*delayTime >= armTime:
            ARMED = not (ARMED)

        pressed_counter = 0
    else:
        print ("X-axis:", x, "V, ", "Y-axis:", y, "V, button: pressed")
        button_pressed = True
        pressed_counter+=1

    print(f"ARMED: {ARMED}")
    print ("---------------------------------------")

    if pressed_counter*delayTime >= exitTime:
        break

    if ARMED:
        armed_led_indicator_on()
        if (abs(X-3.3)<0.01):
            blade_in()

        elif (abs(X-0.0)<0.01):
            blade_out()

        else:
            turn_both_off()
    
    else:
        turn_both_off()
        armed_led_indicator_off()
 
    time.sleep(delayTime/2)


turn_both_off()

for _ in range(2):
    armed_led_indicator_on()
    time.sleep(0.2)
    armed_led_indicator_off()
    time.sleep(0.2)


GPIO.cleanup()

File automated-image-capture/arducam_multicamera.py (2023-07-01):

#!/usr/bin/python3

#  Copyright (c) 2020, Arducam Technology Co., Ltd <http://www.arducam.com>.
#  All rights reserved.
#  
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
#  THIS SOFTWARE IS PROVIDED BY THE COPYRIGHT HOLDERS AND CONTRIBUTORS "AS IS" AND
#  ANY EXPRESS OR IMPLIED WARRANTIES, INCLUDING, BUT NOT LIMITED TO, THE IMPLIED
#  WARRANTIES OF MERCHANTABILITY AND FITNESS FOR A PARTICULAR PURPOSE ARE
#  DISCLAIMED. IN NO EVENT SHALL THE COPYRIGHT HOLDER OR CONTRIBUTORS BE LIABLE FOR ANY
#  DIRECT, INDIRECT, INCIDENTAL, SPECIAL, EXEMPLARY, OR CONSEQUENTIAL DAMAGES
#  (INCLUDING, BUT NOT LIMITED TO, PROCUREMENT OF SUBSTITUTE GOODS OR SERVICES;
#  LOSS OF USE, DATA, OR PROFITS; OR BUSINESS INTERRUPTION) HOWEVER CAUSED AND
#  ON ANY THEORY OF LIABILITY, WHETHER IN CONTRACT, STRICT LIABILITY, OR TORT
#  (INCLUDING NEGLIGENCE OR OTHERWISE) ARISING IN ANY WAY OUT OF THE USE OF THIS
#  SOFTWARE, EVEN IF ADVISED OF THE POSSIBILITY OF SUCH DAMAGE.

#  Copyright (C) 2022, 2023 Anant Sujatanagarjuna

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
import RPi.GPIO as gp
import os, sys, argparse

gp.setwarnings(True)
gp.setmode(gp.BOARD)

gp.setup(7, gp.OUT)
gp.setup(11, gp.OUT)
gp.setup(12, gp.OUT)

FULL="libcamera-still --denoise cdn_hq --awbgain 4.5,3.4 --contrast 1.5 --exposure long -t 3 -n -o {0}"

PREVIEW="libcamera-still -t 0"

LOW="libcamera-still --width 640 --height 480 --denoise cdn_hq --contrast 1.5 --exposure long -t 1 -n -o {0}"

def capture(num, filename, preset=FULL):
    if(num=="A"):
        print('Capturing image from Camera A') 
        i2c = "/usr/sbin/i2cset -y 1 0x70 0x00 0x04"
        os.system(i2c)
        gp.output(7, False)
        gp.output(11, False)
        gp.output(12, True)

    elif(num=="B"):
        print('Capturing image from Camera B') 
        i2c = "/usr/sbin/i2cset -y 1 0x70 0x00 0x05"
        os.system(i2c)
        gp.output(7, True)
        gp.output(11, False)
        gp.output(12, True)

    elif(num=="C"):
        print('Capturing image from Camera C') 
        i2c = "/usr/sbin/i2cset -y 1 0x70 0x00 0x06"
        os.system(i2c)
        gp.output(7, False)
        gp.output(11, True)
        gp.output(12, False)
        

    elif(num=="D"):
        print('Capturing image from Camera D') 
        i2c = "/usr/sbin/i2cset -y 1 0x70 0x00 0x07"
        os.system(i2c)
        gp.output(7, True)
        gp.output(11, True)
        gp.output(12, False)
        
    os.system(preset.format(filename))

if __name__=="__main__":
    parser = argparse.ArgumentParser(description="Wrapper script to capture images using the Arducam Multi-Camera V2.2 board")
    parser.add_argument("-c", "--camera", choices=["A", "B", "C", "D"], required=True)
    parser.add_argument("-o", "--output-file", type=str, help="Output file path", required=True)
    parser.add_argument("-p", "--camera-preset", choices=["FULL", "LOW", "PREVIEW"], required=True)

    args = parser.parse_args()
    capture(args.camera, args.output_file, {"FULL":FULL, "LOW":LOW, "PREVIEW":PREVIEW}[args.camera_preset])

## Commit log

2023-07-01 Add automated image capture camera setup
    [GP8_Case.stp, framePCB.stp]
2023-07-05 Add LCA-Calculations
    [Mushroom_Substrate_Bag__Colonizable_Volume_.xlsx, Mushroom_Substrate_Bucket__Colonizable_Volume_.xlsx]
2023-07-05 Add both harvesting systems
    [Assembly3.iam, Disc.ipt, Disc.stl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]
